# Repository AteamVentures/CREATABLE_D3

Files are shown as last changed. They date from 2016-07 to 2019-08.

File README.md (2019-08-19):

# CREATABLE_D3
The Perfect 3D Printer for Beginners, Educators and Experts.
[creatablelabs.com](http://creatablelabs.com/)

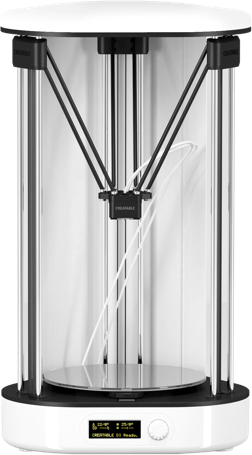
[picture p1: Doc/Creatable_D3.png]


## Open Source Hardware
This product is certified open source hardware. 
[https://certification.oshwa.org/kr000001.html](https://certification.oshwa.org/kr000001.html)

#### Folder Description
 - Hardware : Mainboard, OLED board, Heat bed circuit board and PCB file (The mainboard is working with Allegro of Cadence and the rest is working with Eagle CAD)
 - Firmware : Mainboard firmware [Download](https://github.com/AteamVentures/CREATABLE_D3/raw/master/Firmware/D3_Firmware.zip)  
	1. Connect the printer and computer with the USB cable.
	2. Unzip the file you received from the link above.
	3. Run Cue and execute Machine> Install Custom Firmware ... from the main menu.
	4. Select the hex file from step 2 and click Open.
	5. Wait for uploading to finish.
	6. After completing the upload, operate the printer's menu to execute INFO / SETTINGS> RESTORE DEFAULT.
	7. Execute the leveling and filament insertion according to the first run instructions. If you have already done so, continue to press the button without further action.
	8. Execute INFO / SETTINGS> FIRMWARE VERSION to check the version information.

 - stk500v2 : This it the ATmega2560 bootloader of main board.

#### Cura CREATABLE Edition

- To use the printer, a slicing process is required to convert model files (stl, obj, etc.) to Gcode. To do this, we offer Cura CREATABLE Edition, a slicing software.
- Information on the Cura CREATABLE Edition can be found at the following link.
- [Cura CREATABLE Edition](https://github.com/AteamVentures/CuraCreatableEdition)

#### Folder Description
 -  Hardware: Mainboard, OLED board, Heat bed circuit board and PCB file (The mainboard is working with Cadence's Allegro and the rest with Eagle CAD)
 - Firmware : Mainboard firmware [Download](https://github.com/AteamVentures/CREATABLE_D3/raw/master/Firmware/D3_Firmware.zip)  
	#### How to update firmare
	1. Connect the printer and computer with a USB cable.
	2. Unzip the file you received from the link above.
	3. Execute Cura and run Machine> Install Custom Firmware ... from the main menu.
	4. Select the hex file from step 2 and click "Open".
	5. Wait for uploading to finish.
	6. After completing the upload, operate the printer's menu to execute INFO / SETTINGS> RESTORE DEFAULT.
	7. Execute leveling and filament insertion according to "First run" instructions. If you have already done so, continue to press the button without further action.
	8. Execute INFO / SETTINGS> FIRMWARE VERSION to check the version information.
	- stk500v2 : 메인 보드 ATmega2560 bootloader

#### Differences from Creatable D2 in H/W

- Using Silab's CP2104 for USB connection
- Motor driver A4988 is onboard.
- OLED board: Integrate 2 boards into one board
- Heat bed: Adjusts the resistance value so that it is heated quickly.

#### Cura CREATABLE Edition

- To use the printer, a slicing process is required to convert model files (stl, obj, etc.) into Gcode. To do this, we offer Cura CREATABLE Edition (Cutomized Cura).
- Information about the Cura CREATABLE Edition can be found at the following link.
- [Cura CREATABLE Edition Link](https://github.com/AteamVentures/CuraCreatableEdition)

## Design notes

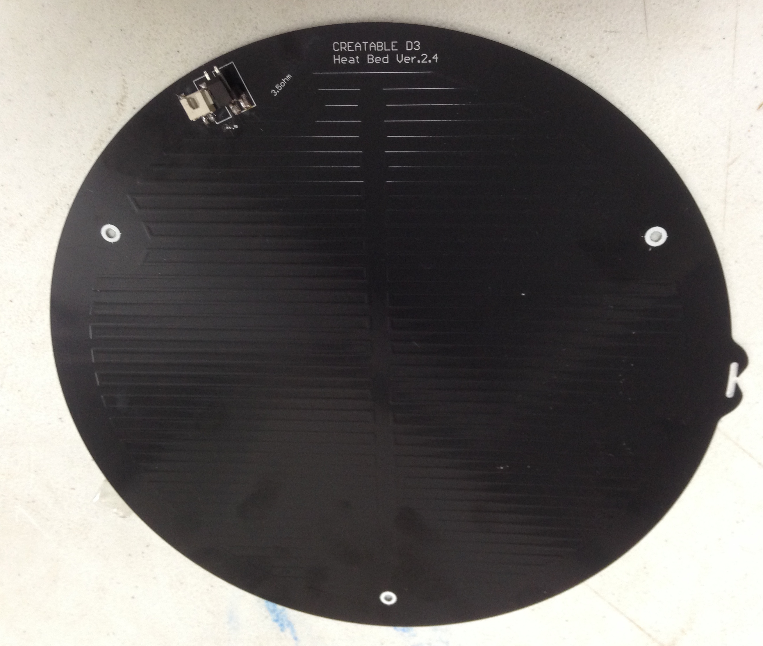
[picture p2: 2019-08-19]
Hardware/HeatBed/heatbed_top.JPG

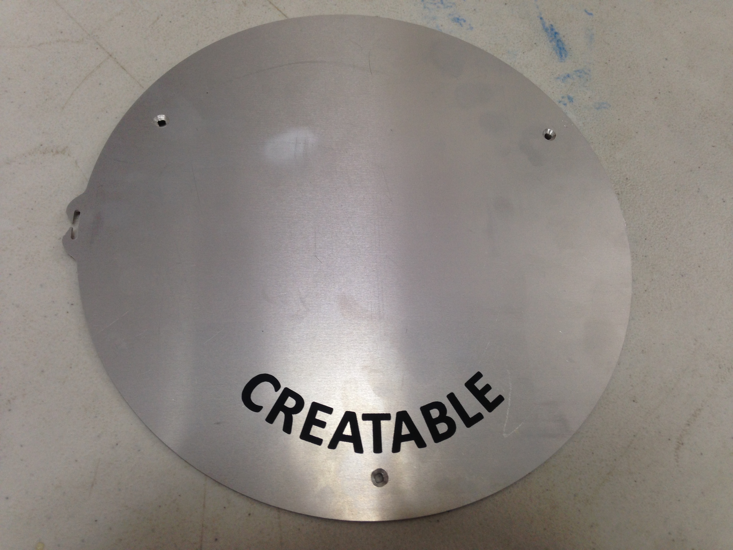
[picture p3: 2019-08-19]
Hardware/HeatBed/heatbed_bottom.JPG

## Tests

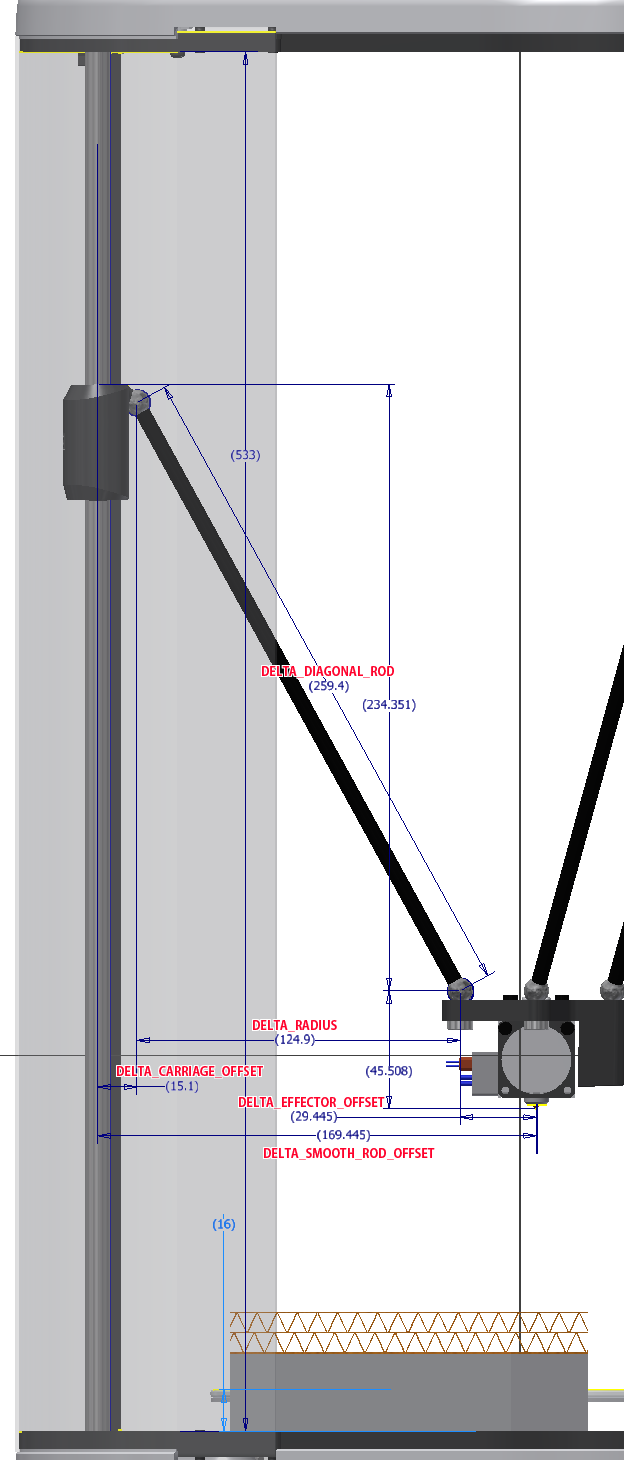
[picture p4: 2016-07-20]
Firmware/D3 Measurements.png

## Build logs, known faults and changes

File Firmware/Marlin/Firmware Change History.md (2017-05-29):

##Firmware Change History
Ver. 1.1.6
- Fix the wrong retraction speed set after load the filament

Ver. 1.1.5
- Supports LED pin of both mainboards(Ver 1.1 & 1.2)
- Add Go home movement before Load / Unload Filament

Ver. 1.1.4
- Fix pin mapping for LED R and G of changed mainboard(Ver 1.2)
- Add definition for selecting cases => #define BALL_BARING_FAN & #define BOARD_VER1_2

Ver. 1.1.3
- Change Error Temperature from 5 to -80

Ver. 1.1.2

- Auto fan control enable. Nozzle temperature is under 50 celcius degrees, fan will be turned off.
- When get serial data, motor will be hold. Originally, motor hold time was 60 seconds. However, we change it to 6000 seconds. 

Ver. 1.1.1

- When get serial data, reset the heat-hold-count.
- Change the default heat-hold-time from 10 minutes to 30 minutes.

Ver. 1.1.0

- Comment Utilities > Clean Nozzle Function
- Change Manual Z Home Position from 232 to 230 for changed bed clip

Ver. 1.0.9

- PID tuning
- Change Kp, Ki, Kd value
- Change PID_MAX Value
- Change PID_FUNCTIONAL_RANGE from 10 to 30

Ver. 1.0.8

- Change DEFAULT_AXIS_STEPS_PER_UNIT Constant for feeder in Configuration.h
- Auto Leveling Code is Disabled

Ver. 1.0.7

- Filament load function debug
- Enable/Disable Unlimit Heating Code add 
	- V130 : Enable Unlimit Heating
	- V131 : Disable Unlimit Heating	
- Change wording (Select Filament)

Ver. 1.0.6

- Delete D2 firmware files
- Change Delta Radius Values in configuration.h file
- Add D3 Delta Radius Values image

Ver. 1.0.5

- While SD Card Printing, stepper deactivate time is changed from 60 to 9999 seconds

Ver. 1.0.4

- Apply 3 point manual leveling
- Add LED control
- Add Buzzer on/off

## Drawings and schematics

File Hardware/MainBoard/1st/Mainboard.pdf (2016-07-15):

## MCU

# RESET XTAL2 XTAL1 AREF

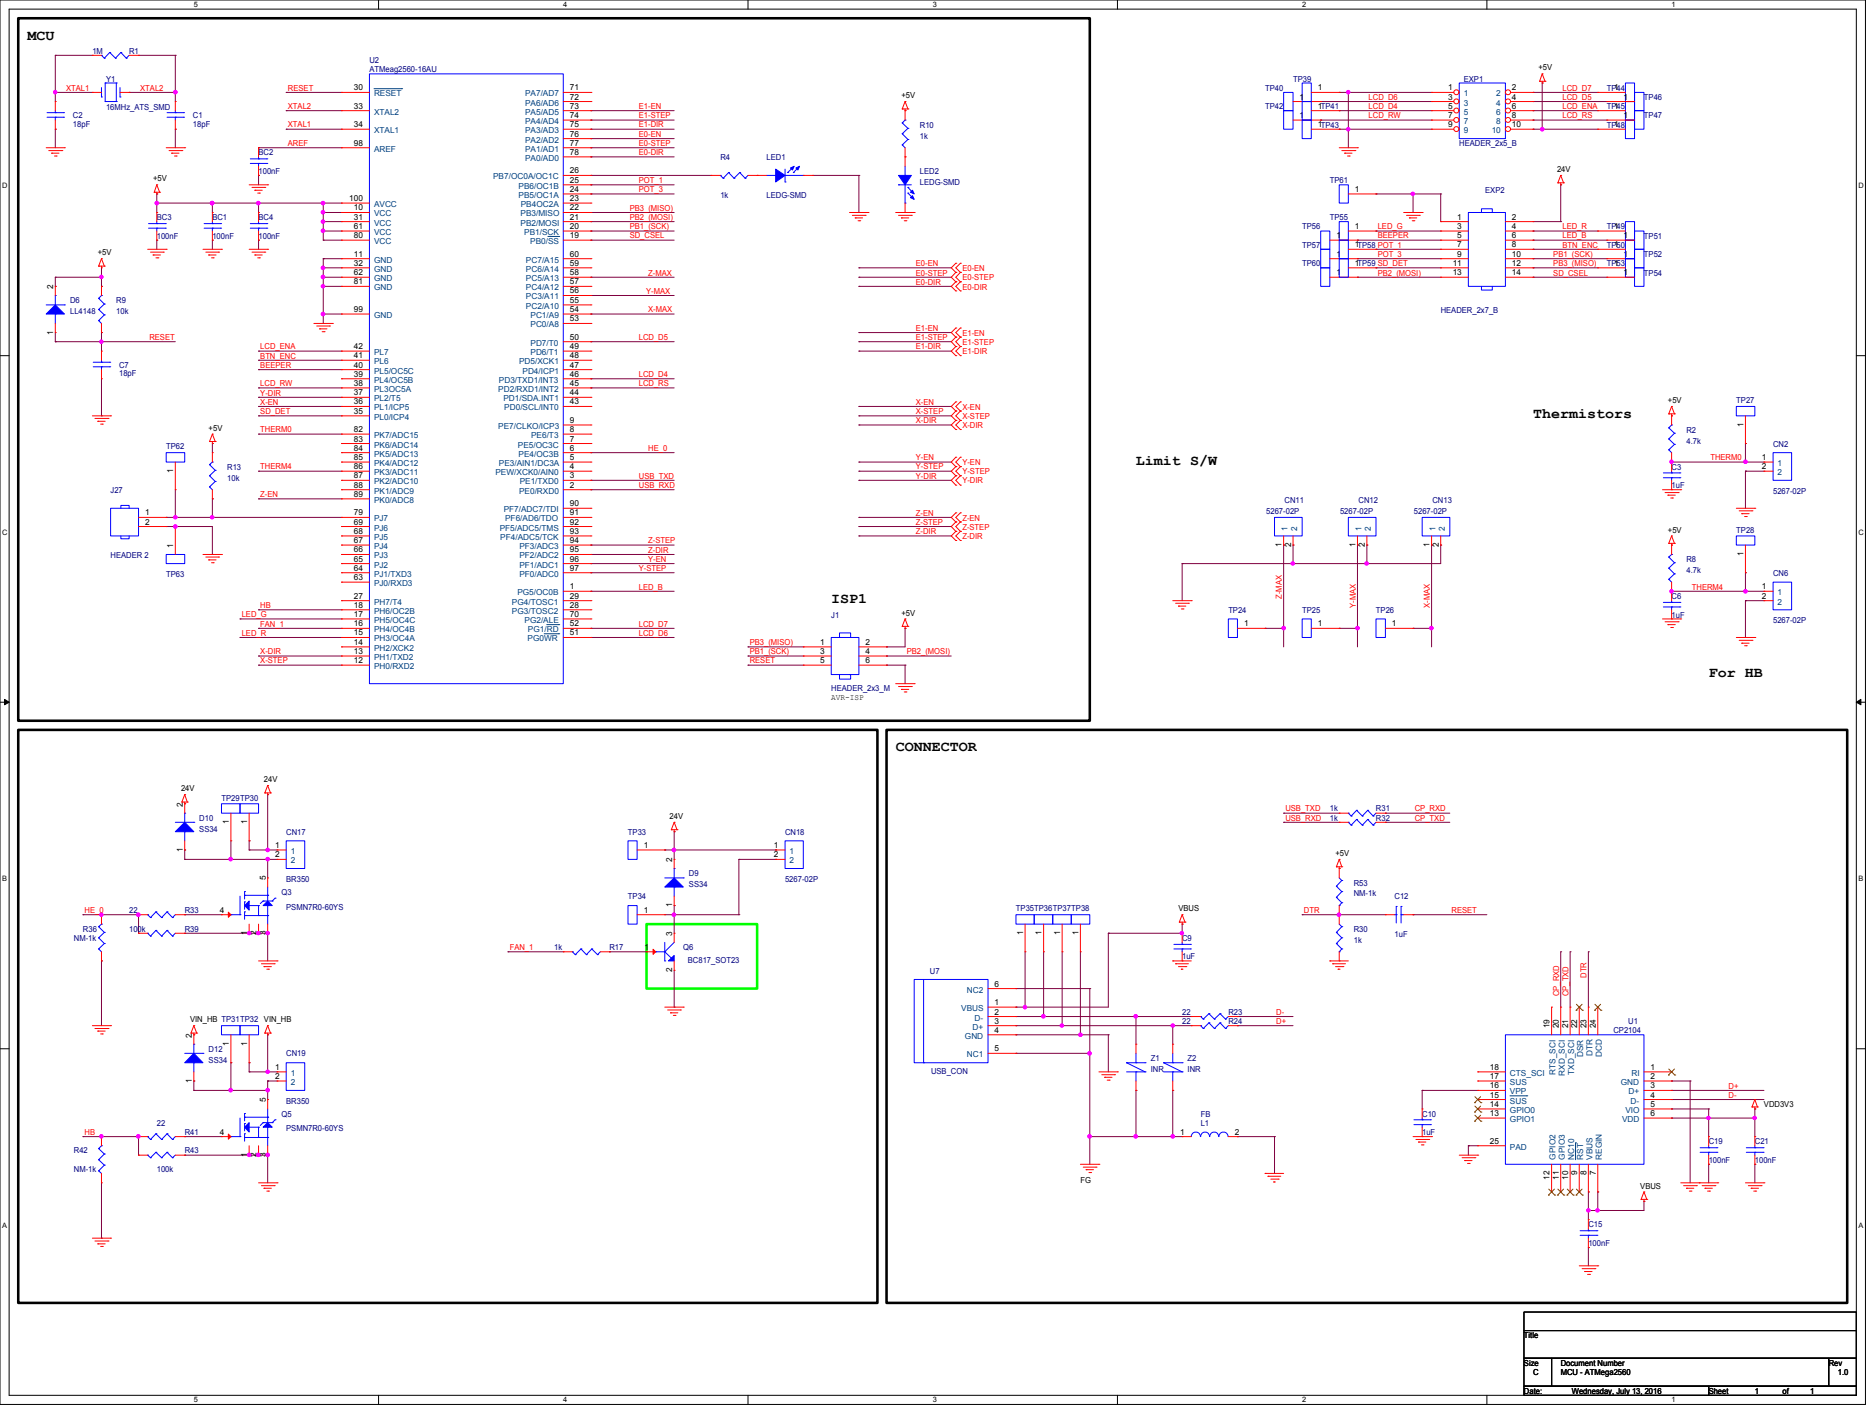
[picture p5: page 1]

## E1-MOT

## E0-MOT

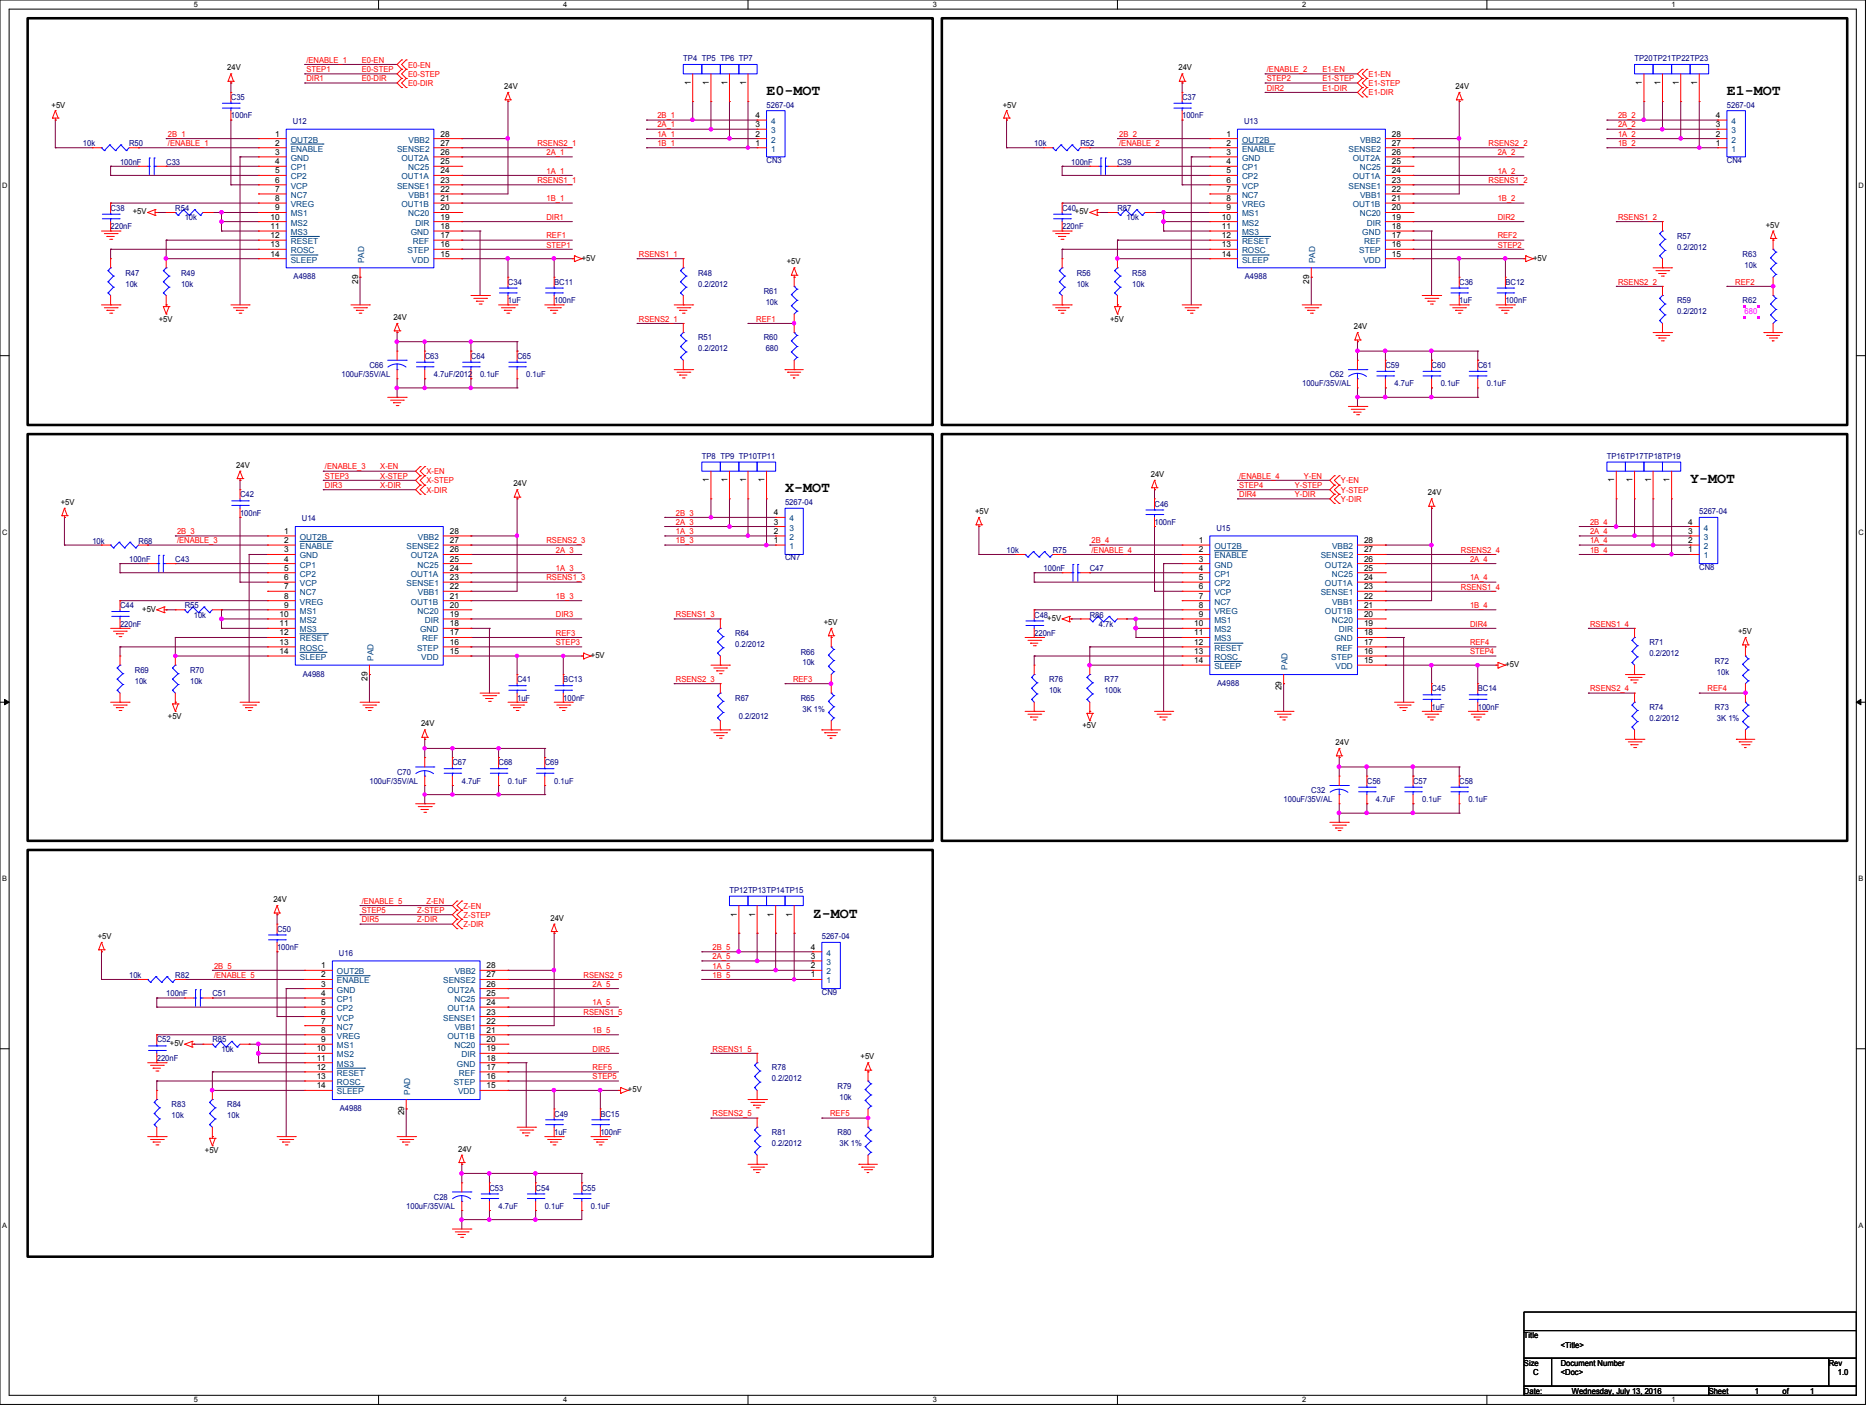
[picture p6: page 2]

# PWR Switch

24V_IN | 24V_OUT

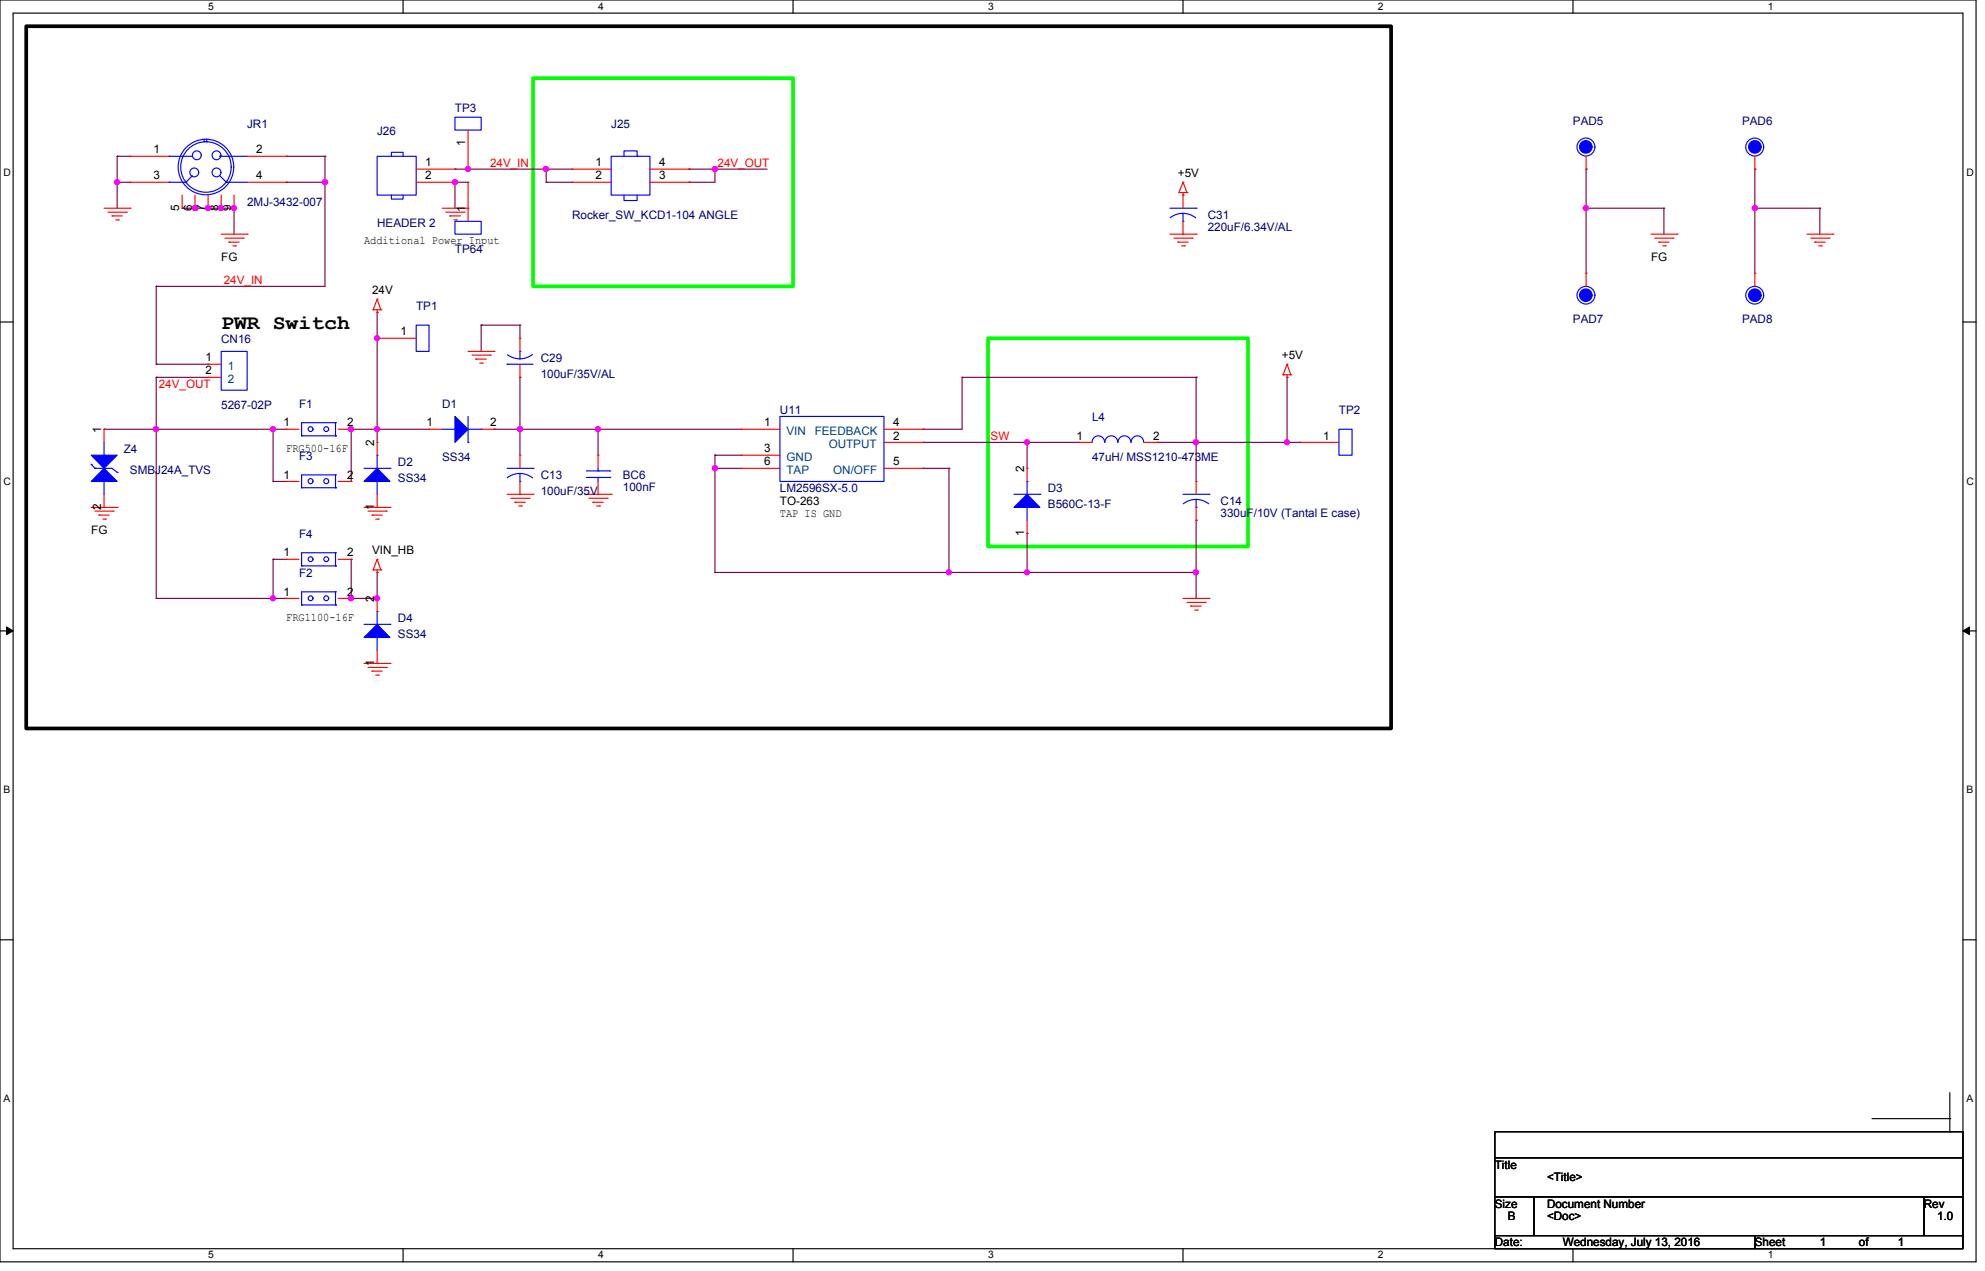
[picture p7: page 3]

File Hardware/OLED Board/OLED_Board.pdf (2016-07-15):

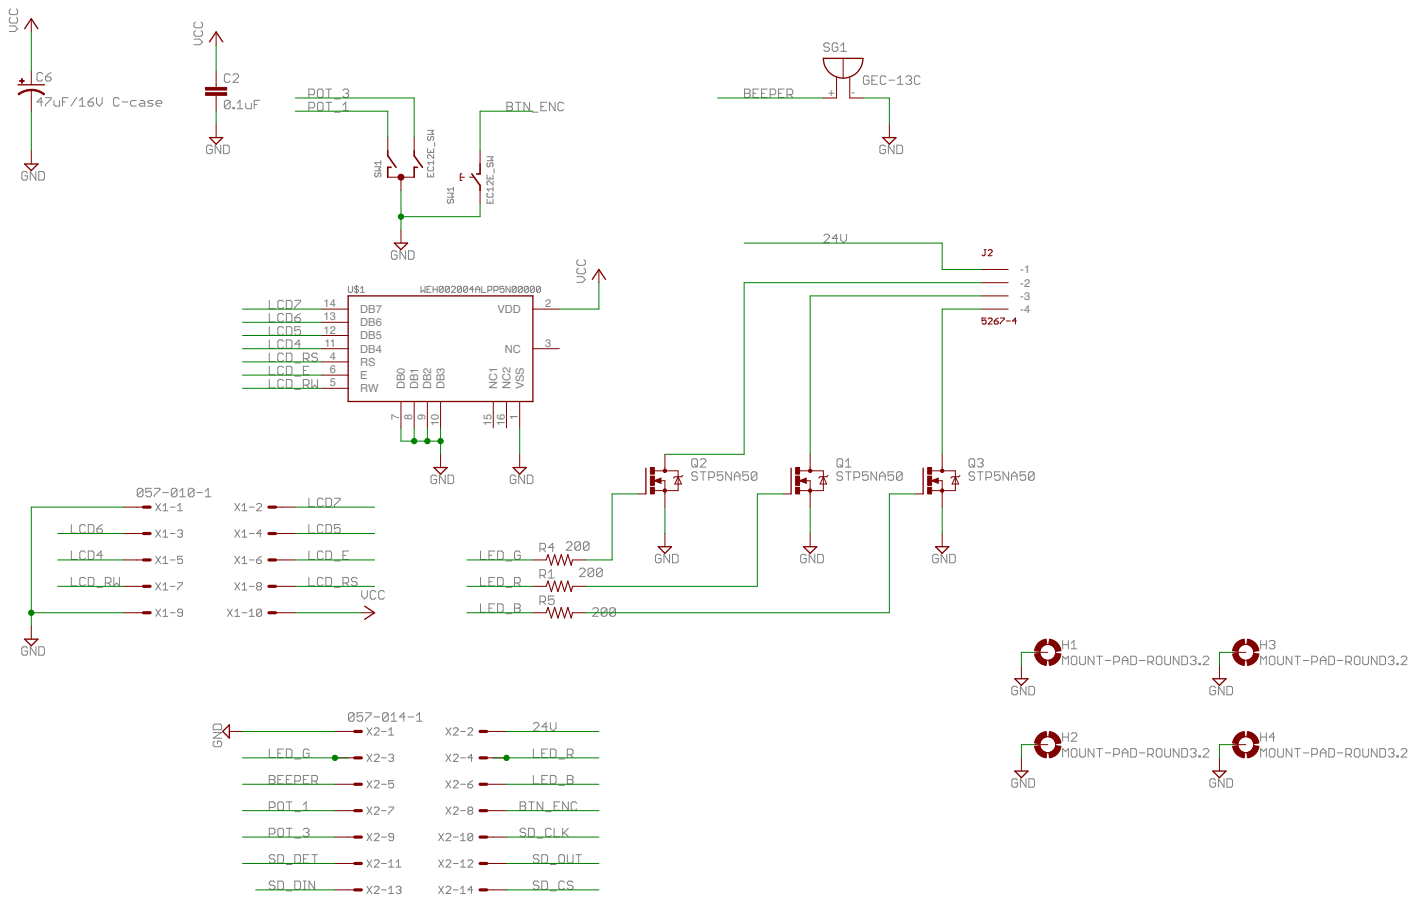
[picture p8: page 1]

VSS 1 VDD 2 NC 3 RS 4 RW 5 E 6 DB0 7 DB1 8 DB2 9 DB3 10 DB4 11 DB5 12 DB6 13 DB7 14 NC1 15 NC2 16 -1-2-3-4 + -

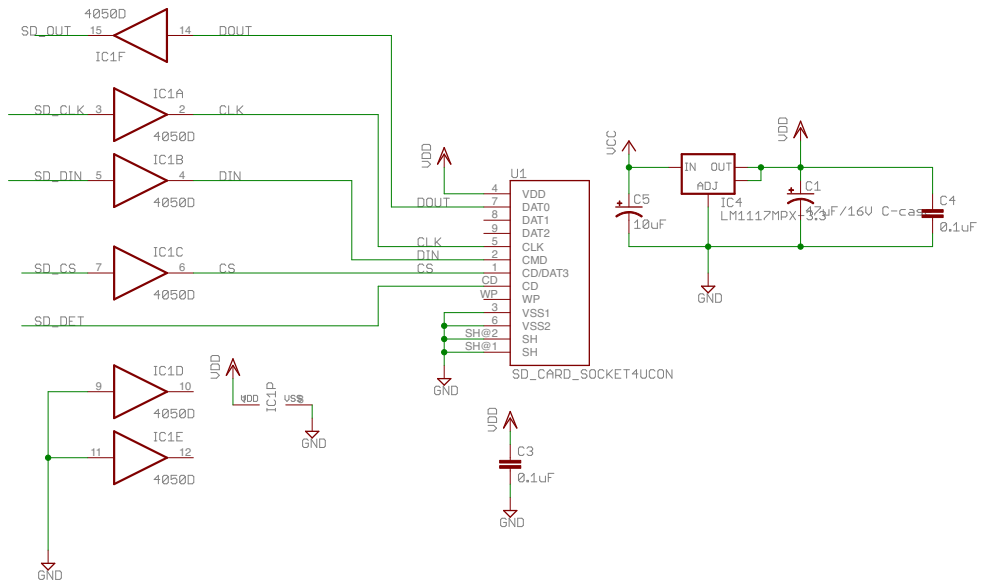
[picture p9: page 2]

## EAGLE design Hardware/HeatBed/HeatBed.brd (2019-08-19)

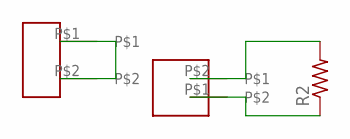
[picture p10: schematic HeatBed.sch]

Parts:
R2: R-US_R0402; R0402
U$2: SMD_WAFER_2; SMD_WAFER_02
U$3: SMD_TERMINAL_2; SMD_5MM_2

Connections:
unnamed: R2.2, U$2.P$2
unnamed: R2.1, U$2.P$1
unnamed: U$3.P$1, U$3.P$2

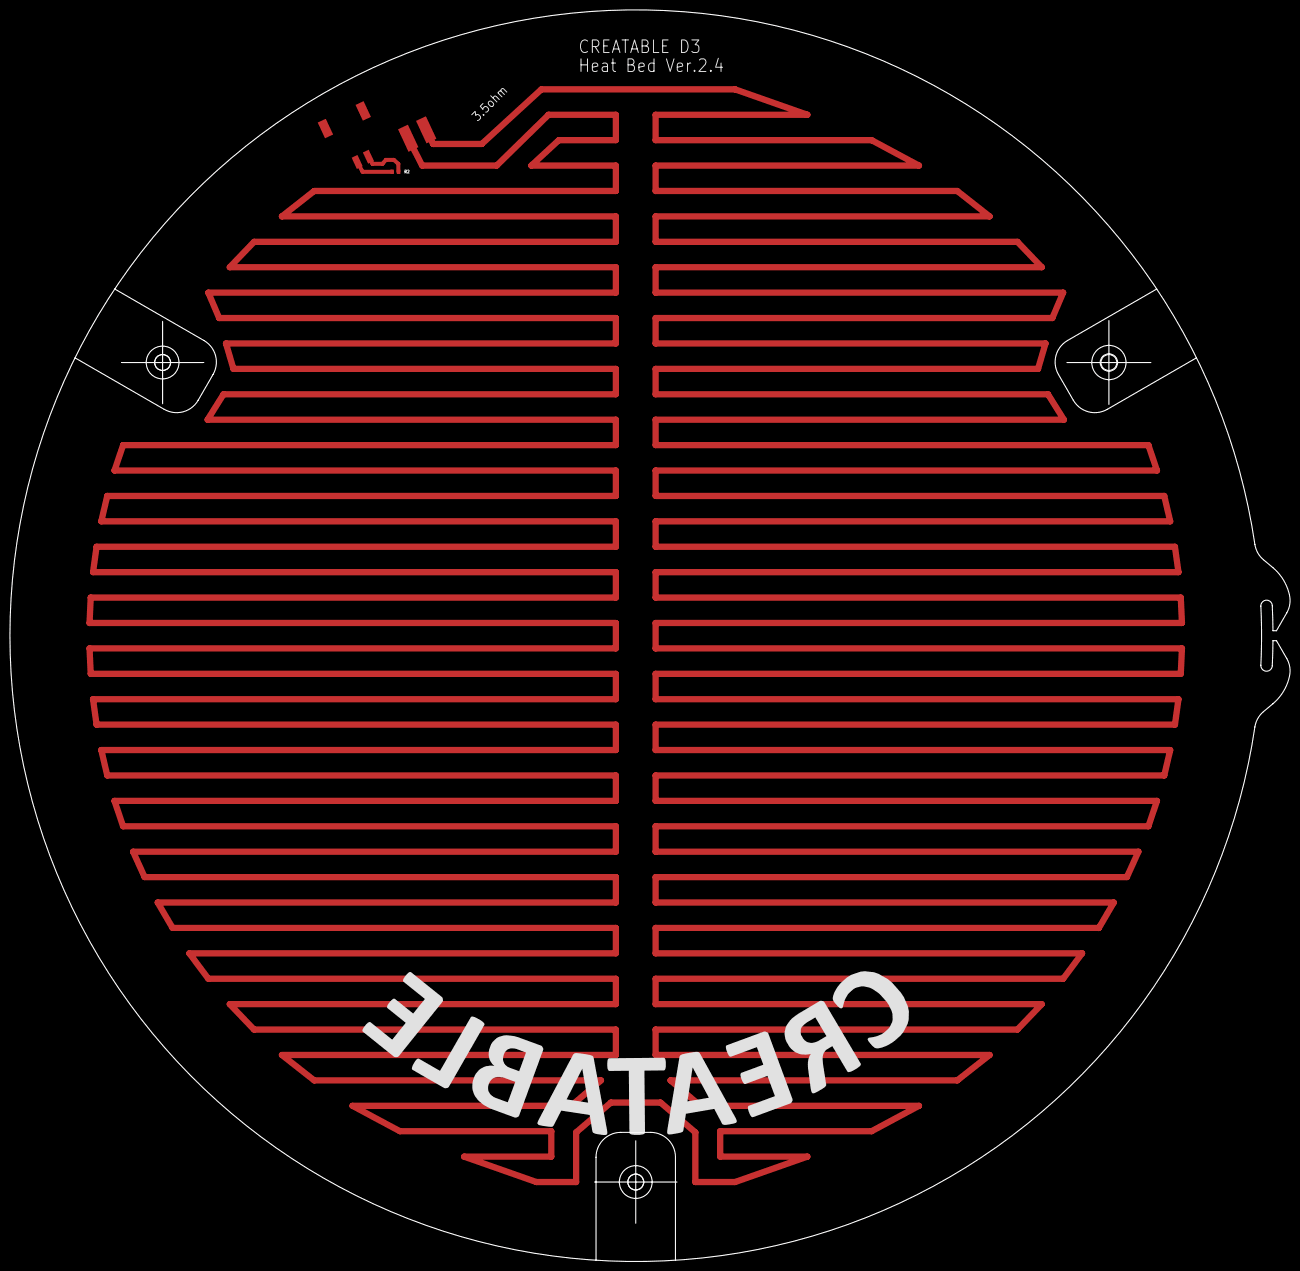
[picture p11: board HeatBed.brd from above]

Board: 2 copper layers, 257.7 x 252.0 mm, 5 parts (1 on the bottom side), 3 nets.

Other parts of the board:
U$1: HEAT_BED2.3(R126_T2.3)
U$4: CREATABLE_WORD

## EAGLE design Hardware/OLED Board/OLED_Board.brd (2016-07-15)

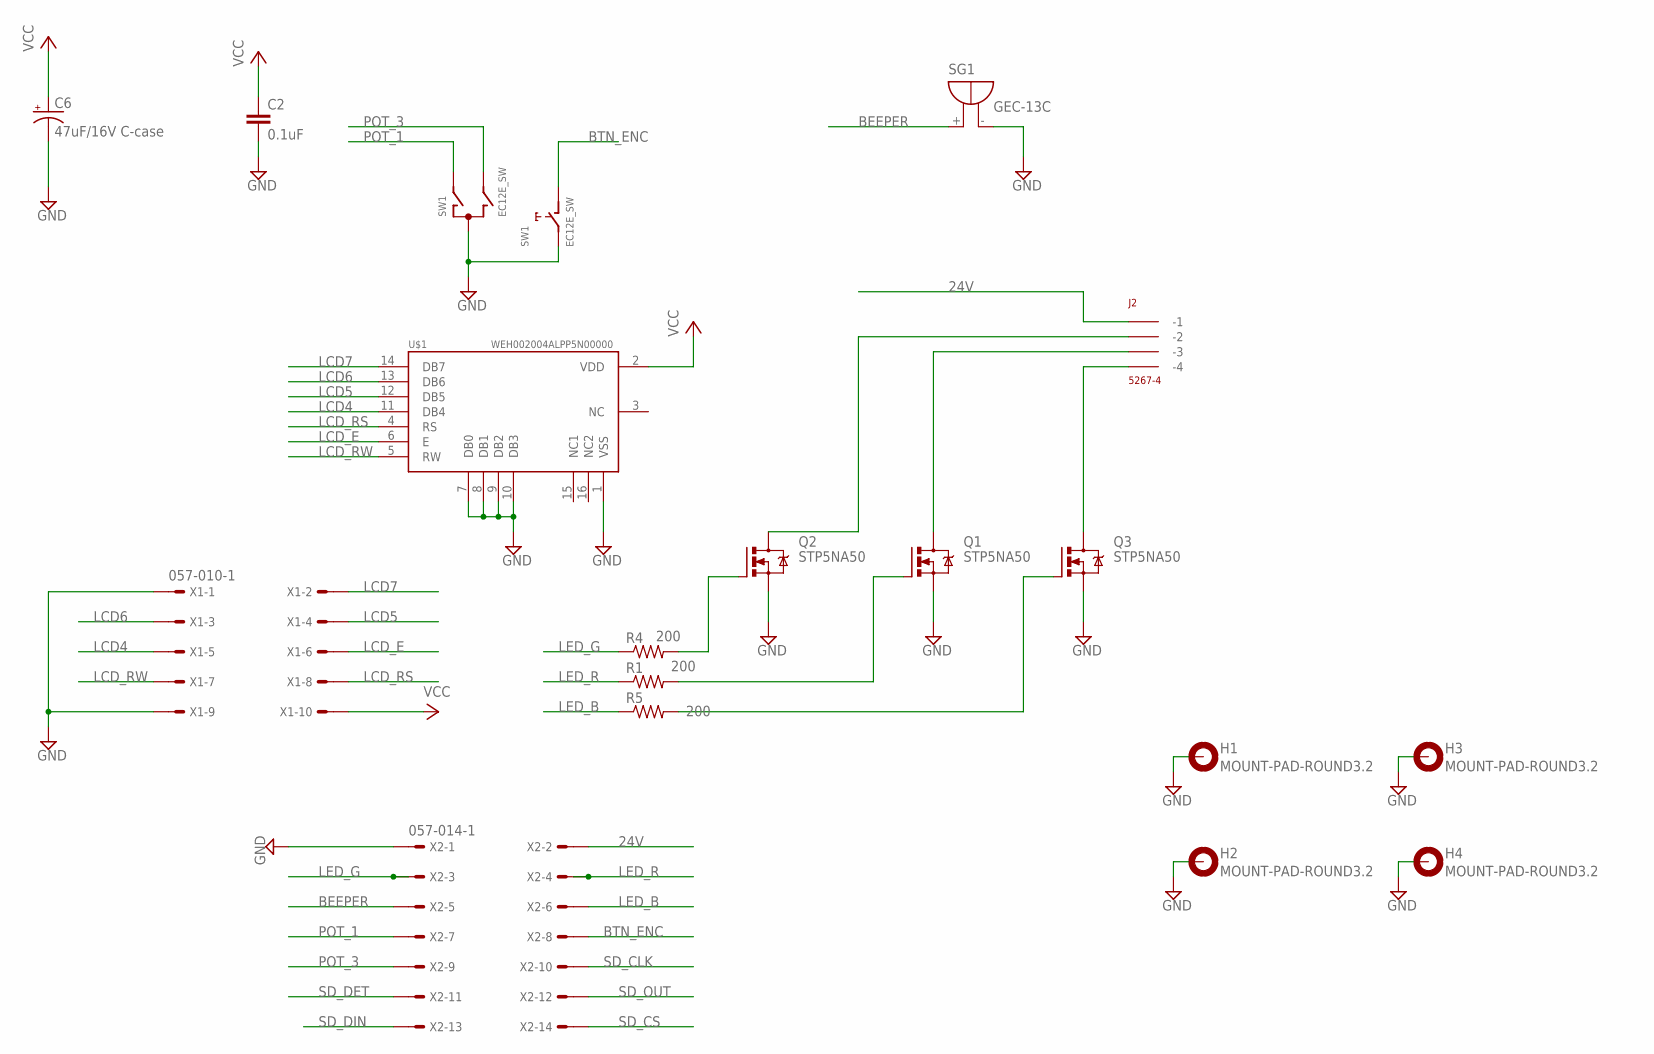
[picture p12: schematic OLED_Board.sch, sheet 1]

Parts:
C2: 0.1uF; C0805
C6: 47uF/16V C-case; EIA6032
H1, H2, H3, H4: MOUNT-PAD-ROUND3.2; 3,2-PAD
J2: 5267-4
Q1, Q2, Q3: STP5NA50; TO220BV
R1, R4, R5: 200; R2012
SG1: GEC-13C; F/TMB
SW1: EC12E_SW; ALPS_EC12E_SW
U$1: OLED; WEH002004ALPP5N00000
X1: 057-010-1
X2: 057-014-1

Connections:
24V: J2.P$1 (-1), X2.2
BEEPER: SG1.+, X2.5
BTN_ENC: SW1.D (1), X2.8
GND: C2.2, C6.P$2 (-), H1.B3,2, H2.B3,2, H3.B3,2, H4.B3,2, Q1.S, Q2.S, Q3.S, SG1.-, SW1.C, SW1.E (2), U$1.1 (VSS), U$1.7 (DB0), U$1.8 (DB1), U$1.9 (DB2), U$1.10 (DB3), X1.1, X1.9, X2.1; also elsewhere on the board
LCD4: U$1.11 (DB4), X1.5
LCD5: U$1.12 (DB5), X1.4
LCD6: U$1.13 (DB6), X1.3
LCD7: U$1.14 (DB7), X1.2
LCD_E: U$1.6 (E), X1.6
LCD_RS: U$1.4 (RS), X1.8
LCD_RW: U$1.5 (RW), X1.7
LED_B: R5.1, X2.6
LED_G: R4.1, X2.3
LED_R: R1.1, X2.4
unnamed: Q2.G, R4.2
unnamed: Q1.G, R1.2
unnamed: Q3.G, R5.2
unnamed: J2.P$2 (-2), Q2.D
unnamed: J2.P$3 (-3), Q1.D
unnamed: J2.P$4 (-4), Q3.D
POT_1: SW1.A, X2.7
POT_3: SW1.B, X2.9
SD_CLK: X2.10; also elsewhere on the board
SD_CS: X2.14; also elsewhere on the board
SD_DET: X2.11; also elsewhere on the board
SD_DIN: X2.13; also elsewhere on the board
SD_OUT: X2.12; also elsewhere on the board
VCC: C2.1, C6.P$1 (+), U$1.2 (VDD), X1.10; also elsewhere on the board

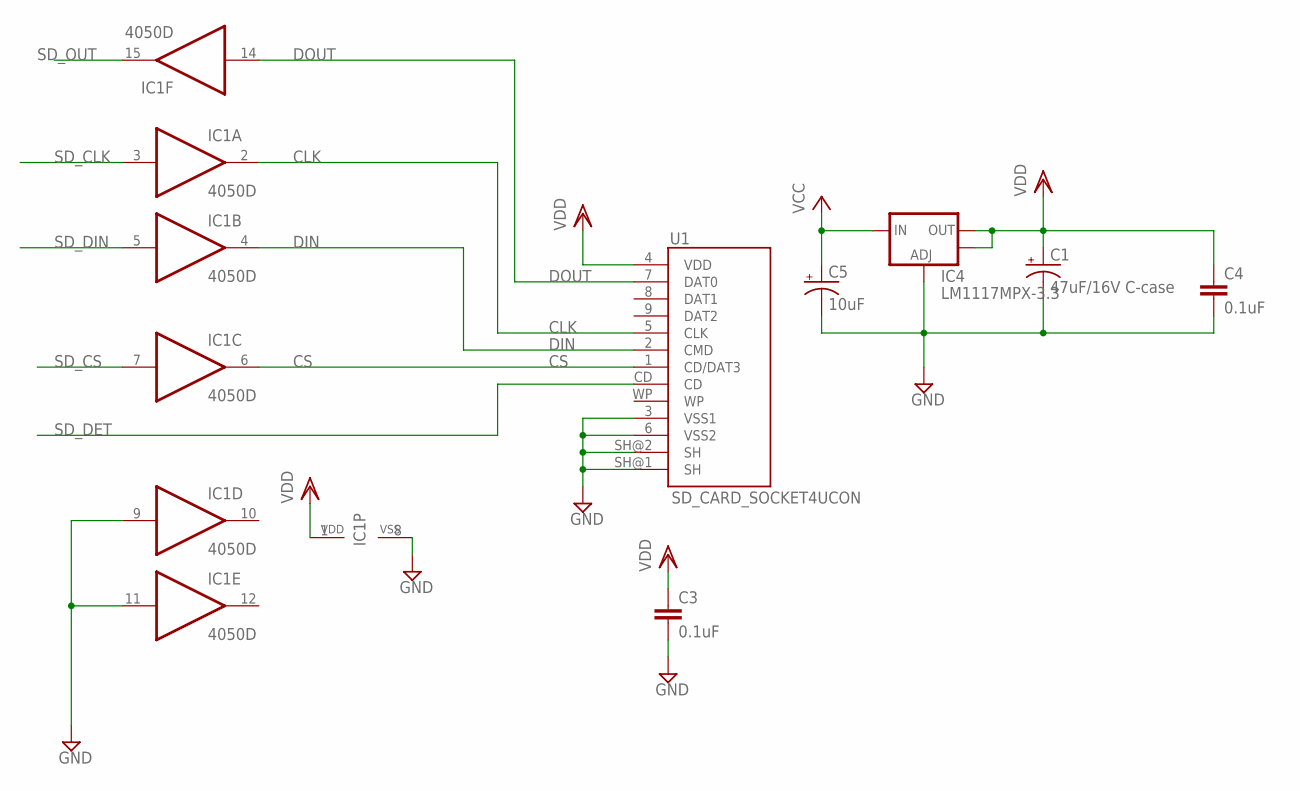
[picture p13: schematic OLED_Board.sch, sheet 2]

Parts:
C1: 47uF/16V C-case; EIA6032
C3, C4: 0.1uF; C0805
C5: 10uF; CT3216
IC1: 4050D; SO16
IC4: LM1117MPX-3.3; SOT223
U1: SD_CARD_SOCKET4UCON; SDCARD_4UCONN

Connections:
CLK: IC1.2 (O), U1.5 (CLK)
CS: IC1.6 (O), U1.1 (CD/DAT3)
DIN: IC1.4 (O), U1.2 (CMD)
DOUT: IC1.14 (I), U1.7 (DAT0)
GND: C1.P$2 (-), C3.2, C4.2, C5.-, IC1.8 (VSS), IC1.9 (I), IC1.11 (I), IC4.1 (ADJ), U1.3 (VSS1), U1.6 (VSS2), U1.SH@1 (SH), U1.SH@2 (SH); also elsewhere on the board
SD_CLK: IC1.3 (I); also elsewhere on the board
SD_CS: IC1.7 (I); also elsewhere on the board
SD_DET: U1.CD; also elsewhere on the board
SD_DIN: IC1.5 (I); also elsewhere on the board
SD_OUT: IC1.15 (O); also elsewhere on the board
VCC: C5.+, IC4.3 (IN); also elsewhere on the board
VDD: C1.P$1 (+), C3.1, C4.1, IC1.1 (VDD), IC4.2 (OUT), IC4.4 (OUT), U1.4 (VDD)

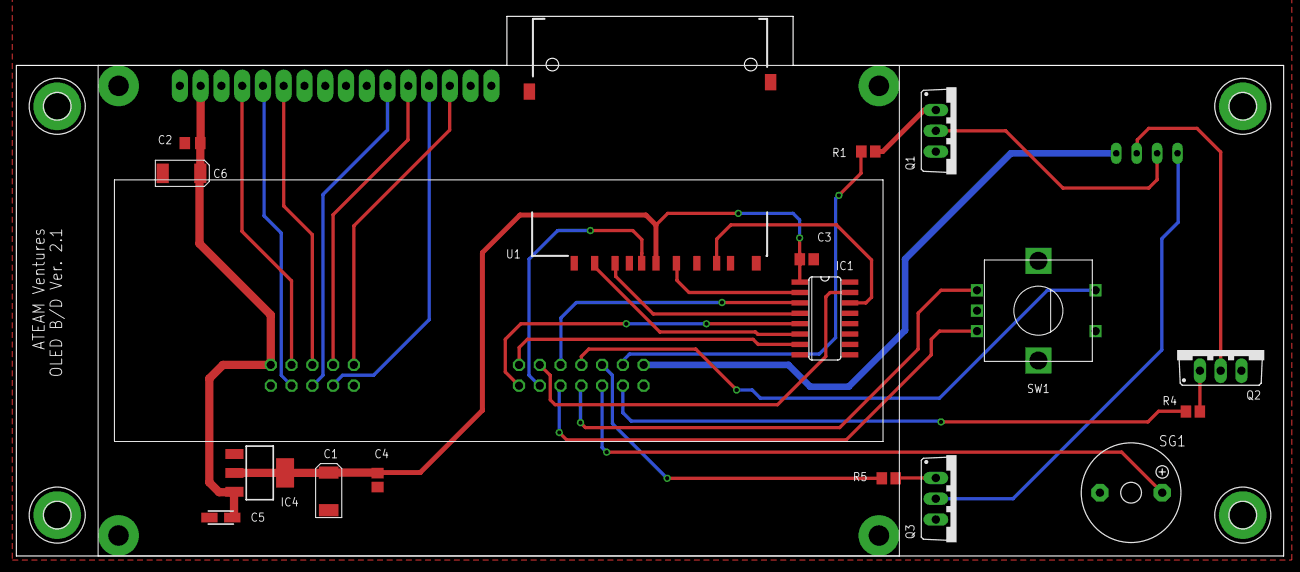
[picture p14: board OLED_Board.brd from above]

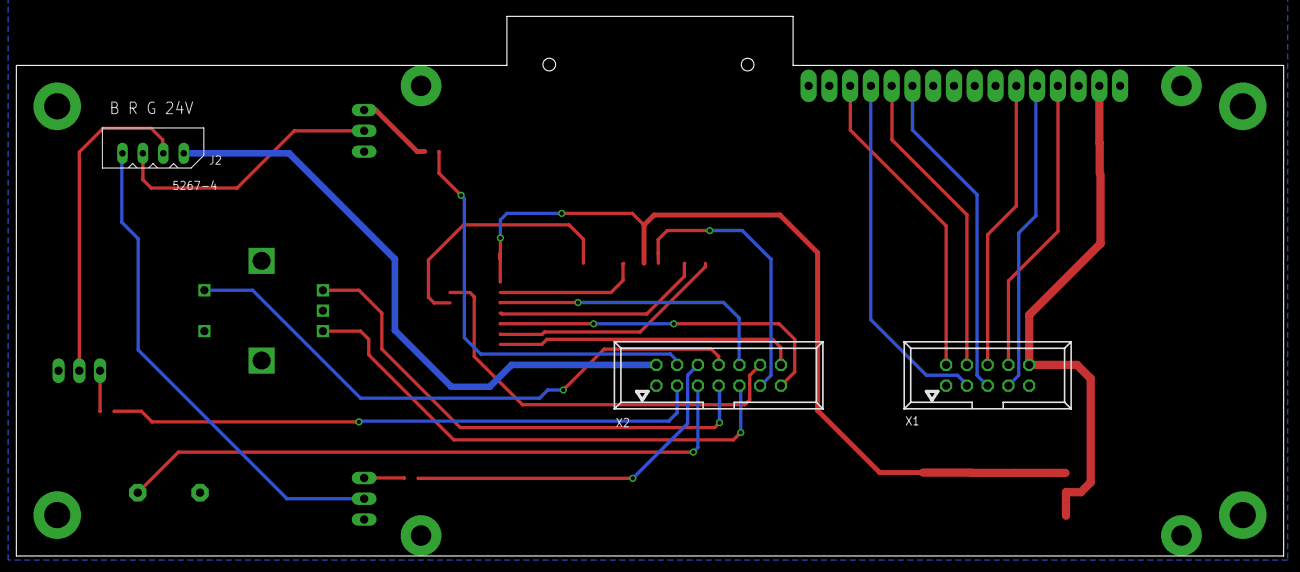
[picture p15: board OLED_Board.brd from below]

Board: 2 copper layers, 155.0 x 66.0 mm, 25 parts (3 on the bottom side), 33 nets.

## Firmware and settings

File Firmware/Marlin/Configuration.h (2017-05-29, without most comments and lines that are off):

#define CONFIGURATION_H
#define STRING_VERSION_CONFIG_H __DATE__ " " __TIME__ // build date and time
#define STRING_CONFIG_H_AUTHOR "Version 1.1.6" // Who made the changes.
#define SERIAL_PORT 0
#define BAUDRATE 250000
#define OLED
#define LED_STRIP
#define FILAMENT_LOAD_TEMP          220
#define FILAMENT_UNLOAD_LEN         700
#define FILAMENT_LOAD_LEN           600  //
#define FILAMENT_LOAD_LEN2          100  //
#define FILAMENT_UNLOAD_SPEED       200
#define FILAMENT_LOAD_SPEED         200
#define FILAMENT_MOVE_ACCELERATION   30
#define DEFAULT_HEAT_HOLD_MINUTE      30
#define AUTO_HEAT_HOLD_DISABLE
#define MOTHERBOARD 80
#define EXTRUDERS 1
#define POWER_SUPPLY 1
#define DELTA
#define DELTA_SEGMENTS_PER_SECOND 200
#define DELTA_DIAGONAL_ROD 259.4 // mm
#define DELTA_SMOOTH_ROD_OFFSET 169.445 // mm
#define DELTA_EFFECTOR_OFFSET 29.445 // mm
#define DELTA_CARRIAGE_OFFSET 15.1 // mm
#define DELTA_RADIUS (DELTA_SMOOTH_ROD_OFFSET-DELTA_EFFECTOR_OFFSET-DELTA_CARRIAGE_OFFSET)
#define DELTA_PRINTABLE_RADIUS 135
#define SIN_60 0.8660254037844386
#define COS_60 0.5
#define DELTA_TOWER1_X -SIN_60*DELTA_RADIUS // front left tower
#define DELTA_TOWER1_Y -COS_60*DELTA_RADIUS
#define DELTA_TOWER2_X SIN_60*DELTA_RADIUS // front right tower
#define DELTA_TOWER2_Y -COS_60*DELTA_RADIUS
#define DELTA_TOWER3_X 0.0 // back middle tower
#define DELTA_TOWER3_Y DELTA_RADIUS
#define DELTA_DIAGONAL_ROD_2 pow(DELTA_DIAGONAL_ROD,2)
#define SAFE_TEMP 50
#define TEMP_SENSOR_0 1407
#if EXTRUDERS > 1
  #define TEMP_SENSOR_1 1407
#else
  #define TEMP_SENSOR_1 0
#endif
#define TEMP_SENSOR_2 0
#define TEMP_SENSOR_BED 1408
#define MAX_REDUNDANT_TEMP_SENSOR_DIFF 10
#define TEMP_RESIDENCY_TIME 3  // (seconds)
#define TEMP_HYSTERESIS 3       // (degC) range of +/- temperatures considered "close" to the target one
#define TEMP_WINDOW     1       // (degC) Window around target to start the residency timer x degC early.
#define HEATER_0_MINTEMP -80
#define HEATER_1_MINTEMP -80
#define HEATER_2_MINTEMP -80
#define BED_MINTEMP -80
#define HEATER_0_MAXTEMP 275
#define HEATER_1_MAXTEMP 275
#define HEATER_2_MAXTEMP 275
#define BED_MAXTEMP 150
#define PIDTEMP
#define BANG_MAX 255 // limits current to nozzle while in bang-bang mode; 255=full current
#define PID_MAX 255 // limits current to nozzle while PID is active (see PID_FUNCTIONAL_RANGE below); 255=full current
  #define PID_FUNCTIONAL_RANGE 30 //10 // If the temperature difference between the target temperature and the actual temperature
  #define PID_INTEGRAL_DRIVE_MAX 255  //limit for the integral term
  #define K1 0.95 //smoothing factor within the PID
  #define PID_dT ((OVERSAMPLENR * 8.0)/(F_CPU / 64.0 / 256.0)) //sampling period of the temperature routine
    #define  DEFAULT_Kp 6.74
    #define  DEFAULT_Ki 0.54
    #define  DEFAULT_Kd 20.99
#define MAX_BED_POWER 255 // limits duty cycle to bed; 255=full current
#define EXTRUDE_MINTEMP 190
#define EXTRUDE_MAXLENGTH (X_MAX_LENGTH+Y_MAX_LENGTH) //prevent extrusion of very large distances.
#define ENDSTOPPULLUPS // Comment this out (using // at the start of the line) to disable the endstop pullup resistors
  #define ENDSTOPPULLUP_XMAX
  #define ENDSTOPPULLUP_YMAX
  #define ENDSTOPPULLUP_ZMAX
  #define ENDSTOPPULLUP_XMIN
  #define ENDSTOPPULLUP_YMIN
  #define ENDSTOPPULLUP_ZMIN
const bool X_MIN_ENDSTOP_INVERTING = false; // set to true to invert the logic of the endstop.
const bool Y_MIN_ENDSTOP_INVERTING = false; // set to true to invert the logic of the endstop.
const bool Z_MIN_ENDSTOP_INVERTING = true; // set to true to invert the logic of the endstop.
const bool X_MAX_ENDSTOP_INVERTING = false; // set to true to invert the logic of the endstop.
const bool Y_MAX_ENDSTOP_INVERTING = false; // set to true to invert the logic of the endstop.
const bool Z_MAX_ENDSTOP_INVERTING = false; // set to true to invert the logic of the endstop.
#if defined(COREXY) && !defined(DISABLE_MAX_ENDSTOPS)
  #define DISABLE_MAX_ENDSTOPS
#endif
#define X_ENABLE_ON 0
#define Y_ENABLE_ON 0
#define Z_ENABLE_ON 0
#define E_ENABLE_ON 0 // For all extruders
#define DISABLE_X false
#define DISABLE_Y false
#define DISABLE_Z false
#define DISABLE_E false // For all extruders
#define INVERT_X_DIR false    // for Mendel set to false, for Orca set to true
#define INVERT_Y_DIR false    // for Mendel set to true, for Orca set to false
#define INVERT_Z_DIR false    // for Mendel set to false, for Orca set to true
#define INVERT_E0_DIR true    // for direct drive extruder v9 set to true, for geared extruder set to false
#define INVERT_E1_DIR false   // for direct drive extruder v9 set to true, for geared extruder set to false
#define INVERT_E2_DIR false   // for direct drive extruder v9 set to true, for geared extruder set to false
#define X_HOME_DIR 1
#define Y_HOME_DIR 1
#define Z_HOME_DIR 1
#define min_software_endstops false // If true, axis won't move to coordinates less than HOME_POS.
#define max_software_endstops true  // If true, axis won't move to coordinates greater than the defined lengths below.
#define X_MAX_POS DELTA_PRINTABLE_RADIUS
#define X_MIN_POS -DELTA_PRINTABLE_RADIUS
#define Y_MAX_POS DELTA_PRINTABLE_RADIUS
#define Y_MIN_POS -DELTA_PRINTABLE_RADIUS
#define Z_MAX_POS MANUAL_Z_HOME_POS
#define Z_MIN_POS 0
#define Z_LEVELING_MIN -10
#define X_MAX_LENGTH (X_MAX_POS - X_MIN_POS)
#define Y_MAX_LENGTH (Y_MAX_POS - Y_MIN_POS)
#define Z_MAX_LENGTH (Z_MAX_POS - Z_MIN_POS)
#define MANUAL_HOME_POSITIONS  // If defined, MANUAL_*_HOME_POS below will be used
#define BED_CENTER_AT_0_0  // If defined, the center of the bed is at (X=0, Y=0)
#define MANUAL_X_HOME_POS 0
#define MANUAL_Y_HOME_POS 0
#define MANUAL_Z_HOME_POS 230// 163 for Tefron 8t magnet, 170 for 4t donut magnet  //175  // For delta: Distance between nozzle and print surface after homing.
#define NUM_AXIS 4 // The axis order in all axis related arrays is X, Y, Z, E
#define HOMING_FEEDRATE {150*60, 150*60, 150*60, 0}  // set the homing speeds (mm/min)
#define XYZ_FULL_STEPS_PER_ROTATION 200
#define XYZ_MICROSTEPS 16
#define XYZ_BELT_PITCH 2
#define XYZ_PULLEY_TEETH 20       // This will be changed into 20 teeth
#define XYZ_STEPS (XYZ_FULL_STEPS_PER_ROTATION * XYZ_MICROSTEPS / double(XYZ_BELT_PITCH) / double(XYZ_PULLEY_TEETH))
#define DEFAULT_AXIS_STEPS_PER_UNIT   {XYZ_STEPS, XYZ_STEPS, XYZ_STEPS, 96.44}  // 17HS24-2104S
#define DEFAULT_MAX_FEEDRATE          {300, 300, 300, 45}    // (mm/sec)
#define DEFAULT_MAX_ACCELERATION      {5000,5000,5000,9000}    // X, Y, Z, E maximum start speed for accelerated moves. E default values are good for skeinforge 40+, for older versions raise them a lot.
#define DEFAULT_ACCELERATION          1000    // X, Y, Z and E max acceleration in mm/s^2 for printing moves
#define DEFAULT_RETRACT_ACCELERATION  3000   // X, Y, Z and E max acceleration in mm/s^2 for retracts
#define DEFAULT_XYJERK                20.0    // (mm/sec)
#define DEFAULT_ZJERK                 20.0    // (mm/sec)
#define DEFAULT_EJERK                 15.0    // (mm/sec)
#define EEPROM_SETTINGS
#define PLA_PREHEAT_HOTEND_TEMP 200
#define PLA_PREHEAT_HPB_TEMP 70
#define PLA_PREHEAT_FAN_SPEED 255   // Insert Value between 0 and 255
#define ABS_PREHEAT_HOTEND_TEMP 240
#define ABS_PREHEAT_HPB_TEMP 90
#define ABS_PREHEAT_FAN_SPEED 255   // Insert Value between 0 and 255
#define SDSUPPORT // Enable SD Card Support in Hardware Console
#define REPRAP_DISCOUNT_SMART_CONTROLLER
 #define ULTIPANEL
 #define NEWPANEL
  #define SDSUPPORT
  #define ULTRA_LCD
    #define LCD_WIDTH 20  // right here..
    #define LCD_HEIGHT 4
#define SOFT_PWM_SCALE 0
#include "Configuration_adv.h"
#include "thermistortables.h"
#define ENABLE_Z_OFFSET

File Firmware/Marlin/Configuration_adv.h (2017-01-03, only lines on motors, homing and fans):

#define CONTROLLERFAN_PIN -1 //Pin used for the fan to cool controller (-1 to disable)
#define EXTRUDER_0_AUTO_FAN_PIN   7//-1
#define EXTRUDER_1_AUTO_FAN_PIN   -1
#define EXTRUDER_2_AUTO_FAN_PIN   -1
#define ENDSTOPS_ONLY_FOR_HOMING // If defined the endstops will only be used for homing
  #define X_HOME_POS MANUAL_X_HOME_POS
  #define Y_HOME_POS MANUAL_Y_HOME_POS
  #define Z_HOME_POS MANUAL_Z_HOME_POS
#define X_HOME_RETRACT_MM 5
#define Y_HOME_RETRACT_MM 5
#define Z_HOME_RETRACT_MM 5
#define MICROSTEP1 LOW,LOW
#define MICROSTEP2 HIGH,LOW
#define MICROSTEP4 LOW,HIGH
#define MICROSTEP8 HIGH,HIGH
#define MICROSTEP16 HIGH,HIGH
#define MICROSTEP_MODES {16,16,16,16,16} // [1,2,4,8,16]
#define DIGIPOT_MOTOR_CURRENT {135,135,135,135,135} // Values 0-255 (RAMBO 135 = ~0.75A, 185 = ~1A)
#define DIGIPOT_I2C_MOTOR_CURRENTS {1.0, 1.0, 1.0, 1.0, 1.0, 1.0, 1.0, 1.0}

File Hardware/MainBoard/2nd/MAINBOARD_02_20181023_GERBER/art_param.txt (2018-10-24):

DEVICE-TYPE           GERBER_RS274X
OUTPUT-UNITS          MM
FILM-SIZE             2400000 1600000
FORMAT                3.5
ABORT-ON-ERROR        NO
SCALE                 1
SUPPRESS-LEAD-ZEROES  NO
SUPPRESS-TRAIL-ZEROES NO
SUPPRESS-EQUAL        YES
UNDEF-APT-CONT        NO

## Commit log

2016-07-15 1st commit
    [HeatBed.brd, HeatBed.sch, Mainboard.DSN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]
2016-07-15 CREATABLE D3 Firmware Ver.1.0.4
    Ver. 1.0.4
    -. Apply 3 point manual leveling
    -. Add LED control
    -. Add Buzzer on/off
    [Configuration.h, Configuration_adv.h, Menu Plans.xlsx]
2016-07-19 Version 1.0.5 Update
    Ver. 1.0.5
    -. While SD Card Printing, stepper deactivate time is changed from 60
    to 9999 seconds.
    [Configuration.h, Configuration_adv.h, Menu Plans.xlsx]
2016-07-20 Version 1.0.6
    - Delete D2 firmware files
    - Change Delta Radius Values in configuration.h file
    - Add D3 Delta Radius Values image
    [Configuration.h, Configuration_adv.h, Menu Plans.xlsx]
2016-07-20 Change Version Notification Method
    [Configuration.h, Configuration_adv.h, Menu Plans.xlsx]
2016-07-20 Version Name Update
    [Configuration.h]
2016-07-21 Ver. 1.0.7
    -. Filament load function debug
    -. Enable/Disable Unlimit Heating Code add
    -. V130 : Enable Unlimit Heating
    -. V131 : Disable Unlimit Heating
    -. Change wording (Select Filament)
    [Configuration.h]
2016-07-21 Disable Autoleveling
    [Configuration.h]
2016-07-21 Ver. 1.0.8
    -. Change DEFAULT_AXIS_STEPS_PER_UNIT Constant for feeder in
    Configuration.h
    -. Auto Leveling Code is Disabled
    [Configuration.h]
2016-08-25 Ver 1.1.0 Update
    -. Comment Utilities > Clean Nozzle Function
    -. Change Manual Z Home Position from 232 to 230 for changed bed clip
    [Configuration.h]
2016-10-10 Ver 1.1.1 Update
    -. When get serial data, reset the heat-hold-count.
    -. Change default heat-hold-time from 10 minutes to 30 minutes.
    [Configuration.h]
2016-10-10 Heat Hold Time related modification
    M104 / M140 / M109 / M190
    + S{temp}
    if temp > 0 disable heathold timeout
    else if temp==0 enable heathold timeout
    [Configuration.h]
2016-10-10 update board coordinate file
    [OLED_Board_centroid.csv]
2016-11-24 Ver. 1.1.2 Update
    - Auto fan control enable. Nozzle temperature is under 50 celcius
    degrees, fan will be turned off.
    - When get serial data, motor will be hold. Originally, motor hold time
    was 60 seconds. However, we change it to 6000 seconds.
    [Configuration.h, Configuration_adv.h]
2016-12-07 Ver. 1.1.3
    - Change Error Temperature from 5 to -80
    [Configuration.h]
2017-01-03 LED pin option & Fan option defined
    [Configuration.h, Configuration_adv.h]
2017-03-13 Ver. 1.1.5 Update
    Ver. 1.1.5
    - Supports LED pin of both mainboards(Ver 1.1 & 1.2)
    - Add Go home movement before Load / Unload Filament
    [Configuration.h]
2017-05-29 Ver 1.1.6 update
    - Fix the wrong retraction speed set after load the filament
    [Configuration.h]
2018-10-24 Rev2. Add
    [MAINBOARD_02_20181023.DSN, MAINBOARD_02_20181023.brd, Mainboard.DSN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]
2019-08-19 upload gerber
    [HeatBed.brd]

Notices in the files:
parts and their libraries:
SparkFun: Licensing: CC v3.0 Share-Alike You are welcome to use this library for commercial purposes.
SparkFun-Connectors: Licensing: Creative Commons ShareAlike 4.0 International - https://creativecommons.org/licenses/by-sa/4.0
